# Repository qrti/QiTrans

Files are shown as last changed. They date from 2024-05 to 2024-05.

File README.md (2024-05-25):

# **QI Transmission**

### Wireless Energy Transmission
<br>

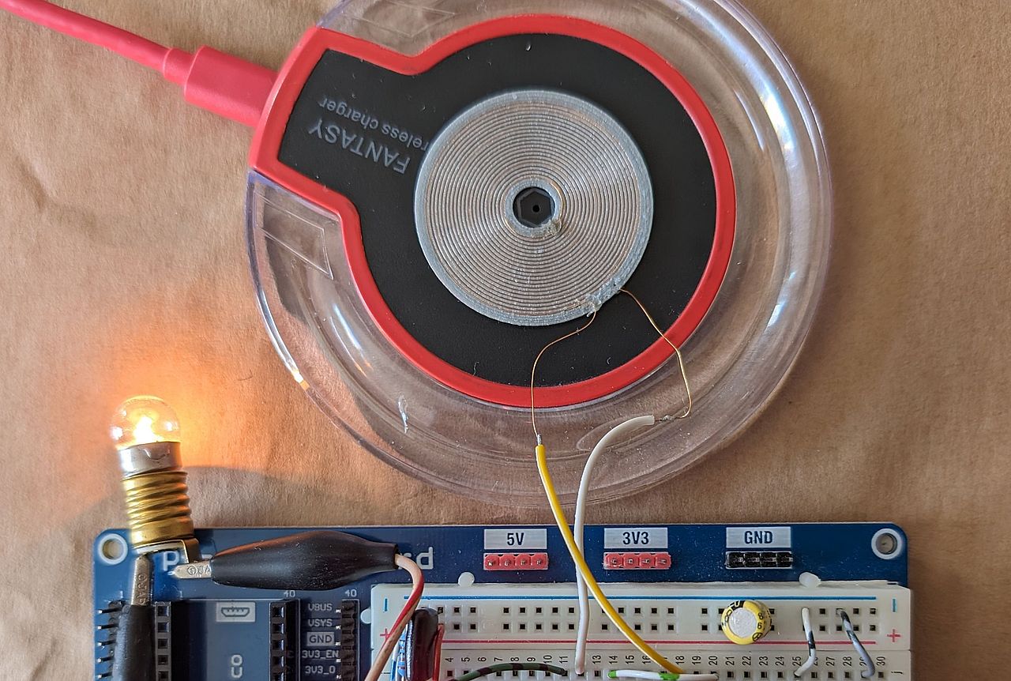
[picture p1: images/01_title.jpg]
<br>
<br>

## Description
Wireless chargers that comply with the Qi standard for charging mobile phones are inexpensive and widely available. Why not experiment a bit with the charger to wirelessly charge a (self-built) battery device, for example? Simply placing a coil on the charger to tap into the power is unfortunately not sufficient. A data transmission embedded in the energy flow according to the Qi protocol must initiate and then continuously maintain the power flow.

In this project, an inexpensive AVR controller with suitable hardware and software is used, and a simple method for manufacturing a flat coil is described.
<br>

## Soft- and Hardware
[**-> Source**](source)  

Breadboard Build, an old fashioned bulb is being lit  
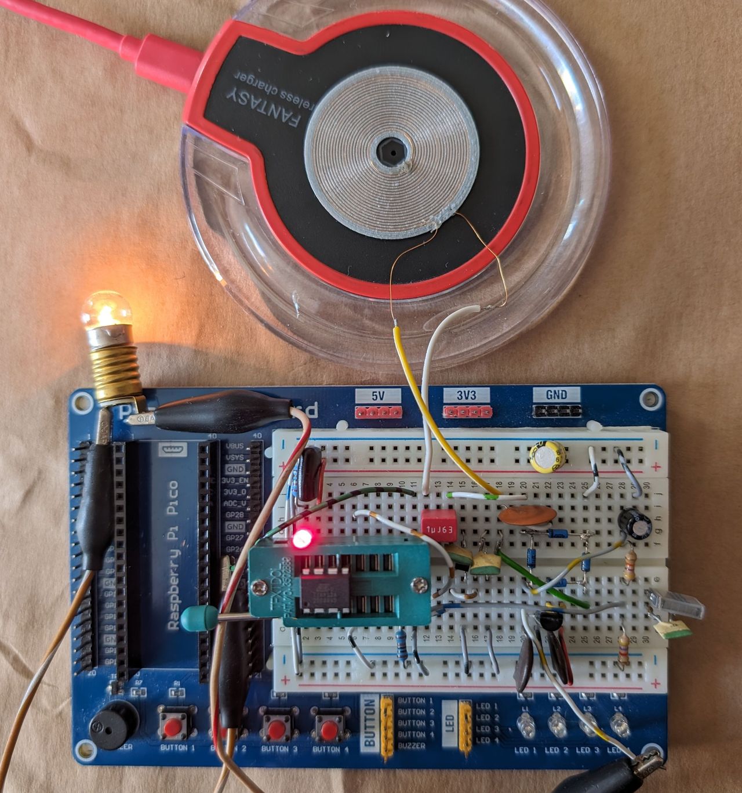
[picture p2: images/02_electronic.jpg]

<br>

Schematic (click to enlarge)  
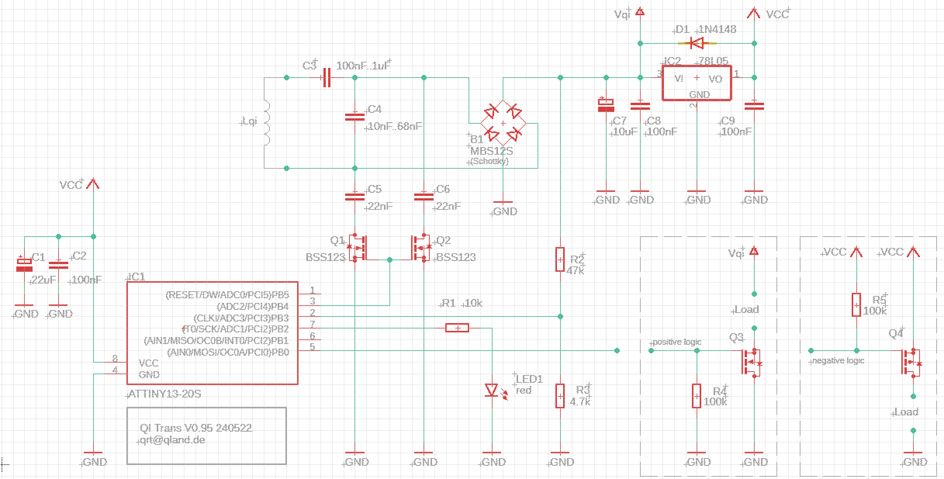
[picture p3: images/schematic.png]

<br>

# Flat Coil  
Two STL files for coils are in the repository, the 3d printer nozzle diameter  
for these prints must be 0.4 mm, you can try to fabricate more dense coils  
with 0.2 mm nozzles  
[-> wire 0.21 mm nozzle 0.4 mm](stl/qi_coil_021_04.stl)  
[-> wire 0.3 mm nozzle 0.4 mm](stl/qi_coil_03_04.stl)
<br>
<br>

Some examples for flat coils, a commercial available flat coil, a self winded  
round one a coil extracted from a hard disk and a self made oval one  
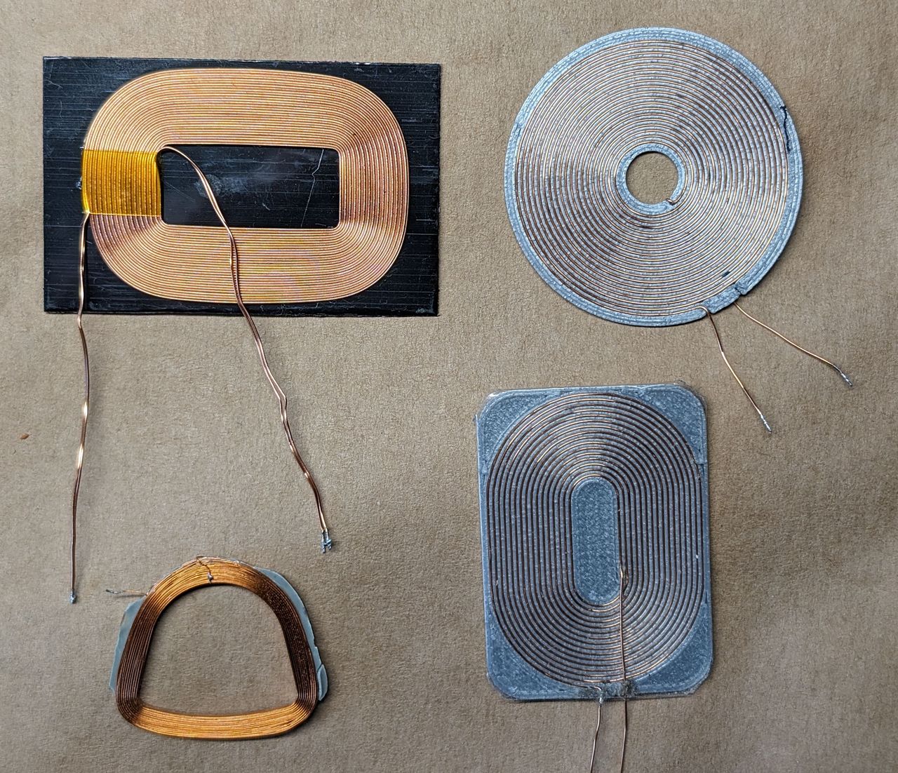
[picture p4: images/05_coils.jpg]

<br>

An easy method of winding a flat coil is to 3D print a carrier with grooves  
to sink in enameled copper wire, if diameters of wire and groove match, no  
glue is necessary to keep the wire on track  
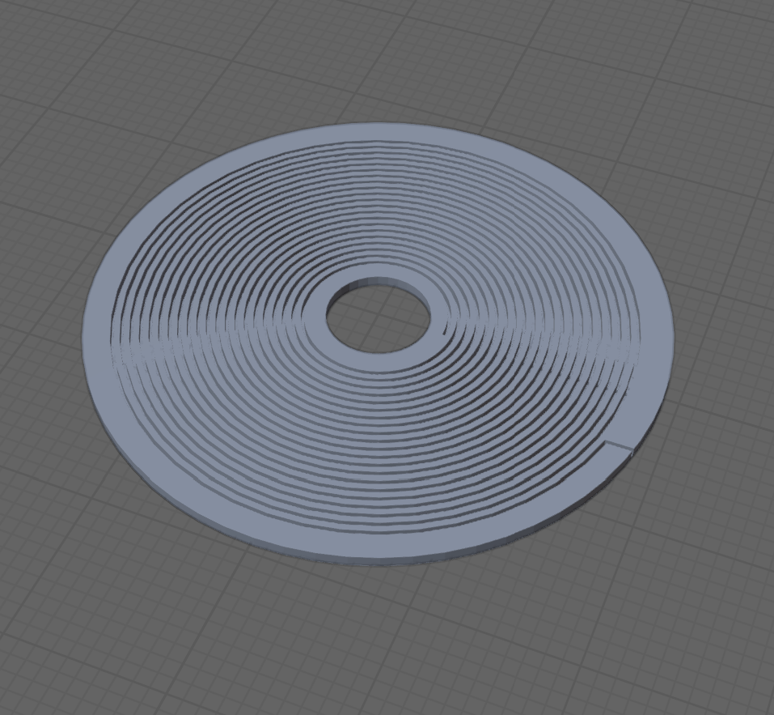
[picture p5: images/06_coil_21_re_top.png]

<br>  

Bottom side with groove to lead the wire outside  
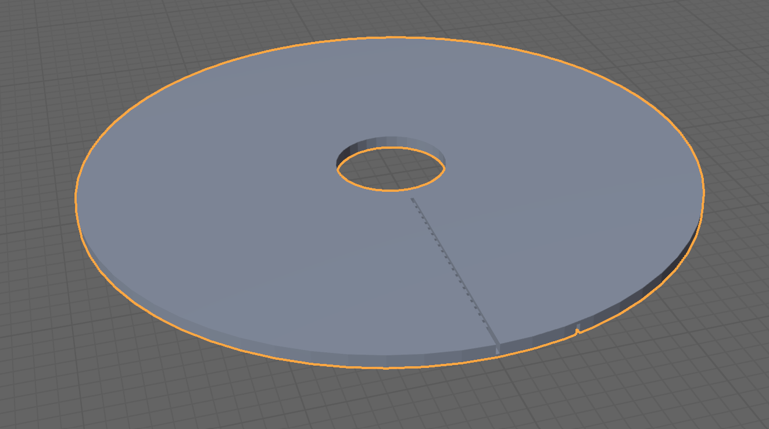
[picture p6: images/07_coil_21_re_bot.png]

<br>

While commercial available flat coils are able to deliver some ampere, these  
self made coils are cheap and easy to wind but will deliver some 100 mA only  
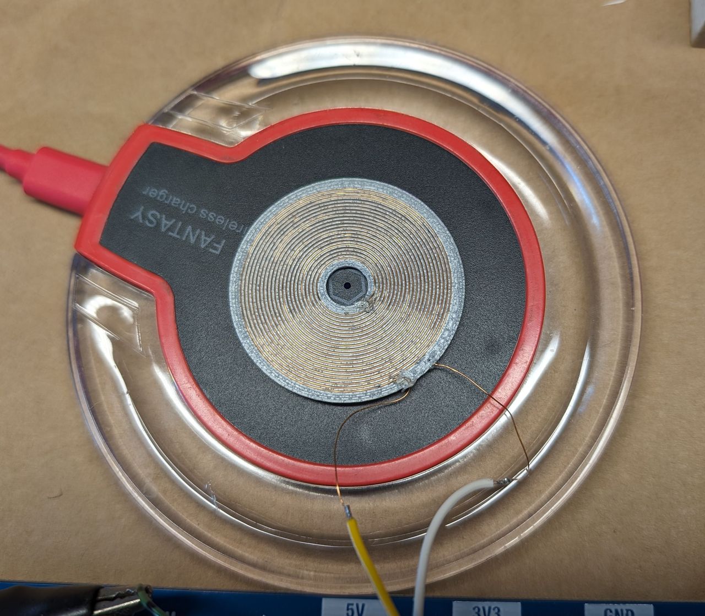
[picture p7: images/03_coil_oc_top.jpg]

<br>

Bottom side  
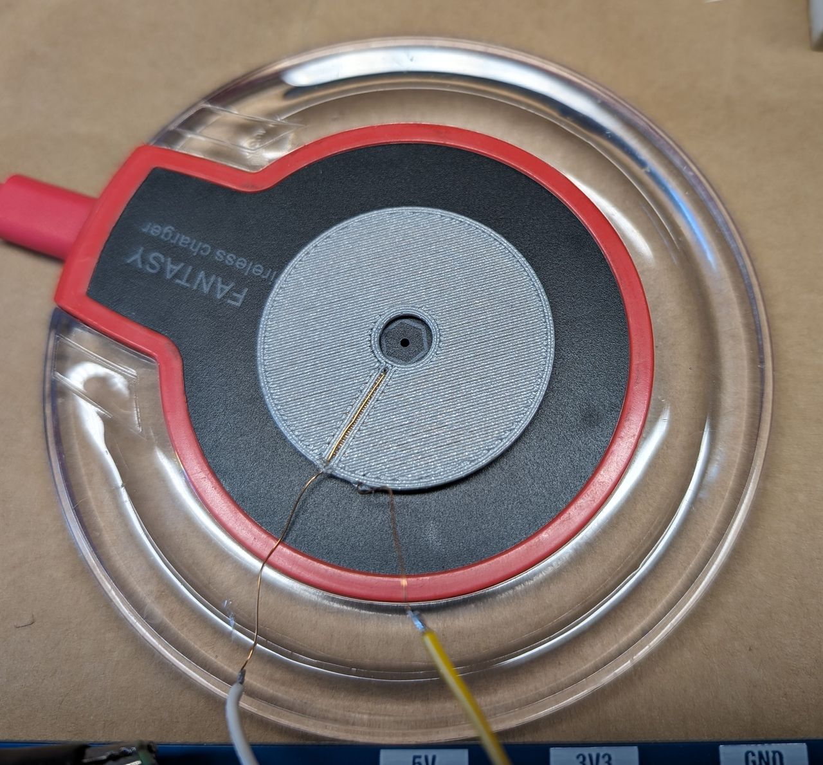
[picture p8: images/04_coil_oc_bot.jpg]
<br>
<br>

Ferro foils on the back of the flat coils will enhance efficiency of wireless  
energy transmission, only **pure** ferro foils for sticking magnets on it, not the  
self magnetic ones, will work  
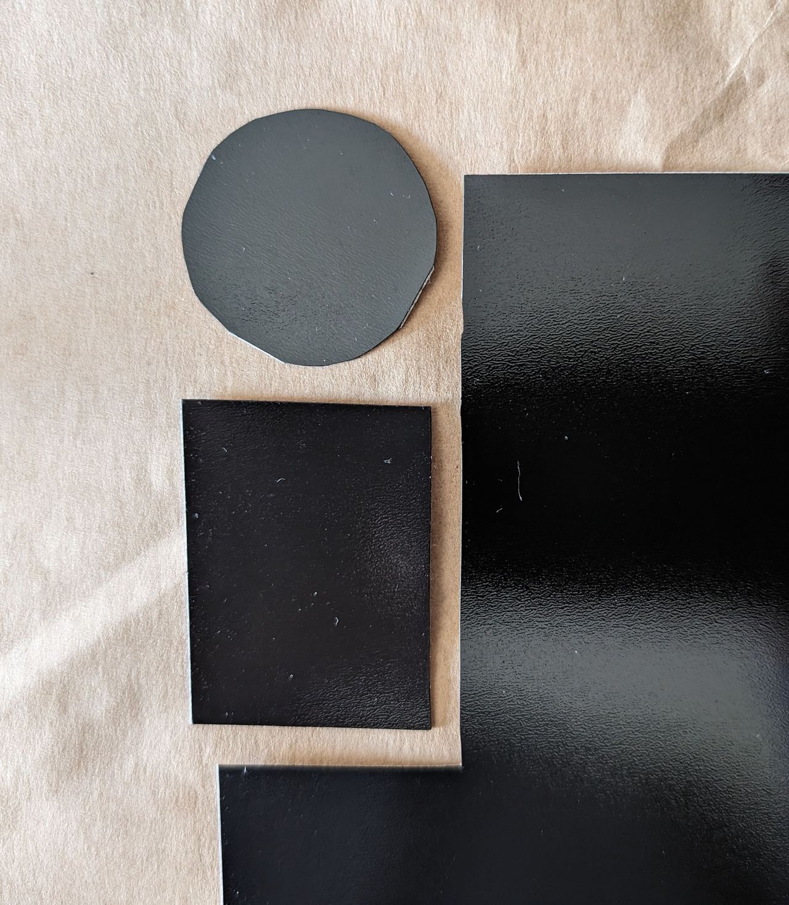
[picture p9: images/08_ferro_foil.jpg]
<br>
<br>

<br>
<br>

**Edited and Developed with vsCode**  
https://code.visualstudio.com/  

<br>

---

[qrt@qland.de](mailto:qrt@qland.de) 240524

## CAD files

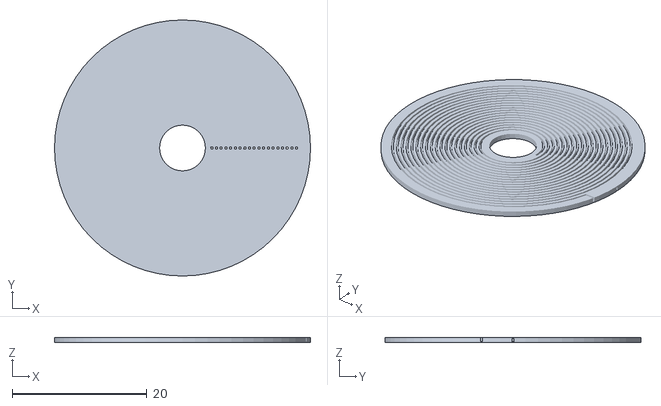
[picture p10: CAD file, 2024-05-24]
stl/qi_coil_03_04.stl
38.0 x 38.0 x 0.8

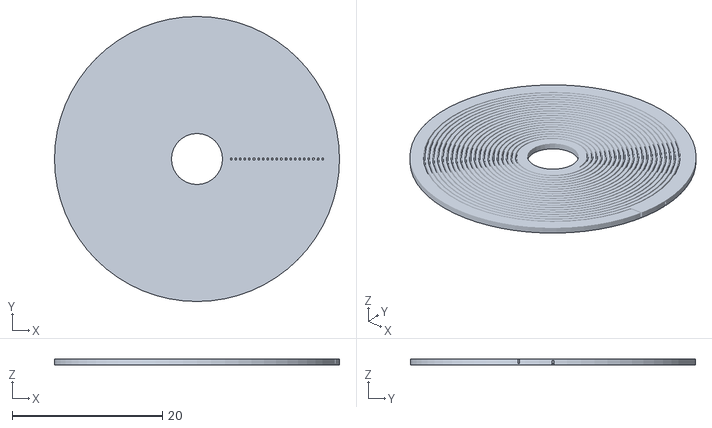
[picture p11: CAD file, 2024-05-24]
stl/qi_coil_021_04.stl
38.0 x 38.0 x 0.8

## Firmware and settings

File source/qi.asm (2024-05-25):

;qi.asm V0.9 QRT240524
;
;ATTINY13 - - - - - - - - - - - - - - - - - - - - - - - - - -
;fuse bits  76543210   low
;SPIEN      0|||||||   (default on)
;EESAVE      1||||||   (default off)
;WDTON        1|||||   (default off)
;CKDIV8        1||||   no clock div during startup
;SUT1..0        00||   00 - 14 CK / 01 - 14 CK + 4 ms /  / 10 - 14 CK + 64 ms
;CKSEL1..0        10   01 - 4.8 / 10 - 9.6 MHz system clock
;           01110010   0x72
;
;fuse bits     43210   high
;SELFPRGEN     1||||   (default off)
;DWEN           1|||   (default off)
;BODLEVEL1..0    10|   00 - 4.3 / 01 - 2.7 / 10 - 1.8 V / 11 - default off
;RSTDISBL          1   (default off)
;              11101   0xfd
;
;V0.9  initial version
;
;-------------------------------------------------------------------------------
;       logic           MOSFET      ground              U load      
; 0     negative        P           uC                  uC          
; 1     positive        N           drain of MOSFET     QI          
.define LOADLOGIC   1                   

;-------------------------------------------------------------------------------

;.device ATtiny13A
.include "tn13Adef.inc"

;-------------------------------------------------------------------------------

.cseg
.org $0000
rjmp main                               ;Reset Handler
;.org $0001
;rjmp EXT_INT0                           ;External Interrupt0 Handler
;.org $0002
;rjmp PCINT0                             ;Pin Change Interrrupt Handler
;.org $0003
;rjmp TIM0_OVF                           ;Timer0 Overflow Handler
;.org $0004
;rjmp EE_RDY                             ;EEPROM Ready Handler
;.org $0005
;rjmp ANA_COMP                           ;Analog Comparator Handler
;.org $0006
;rjmp TIM0_COMPA                         ;Timer0 Compare A
;.org $0007
;rjmp TIM0_COMPB                         ;Timer0 CompareB Handler
;.org $0008
;rjmp WATCHDOG                           ;Watchdog Interrupt Handler
;.org $0009
;rjmp ADC                                ;ADC Conversion Handler

;-------------------------------------------------------------------------------

.def    a0          =   r0              ;main registers set a
.def    a1          =   r1
.def    a2          =   r2
.def    a3          =   r3
.def    a4          =   r24             ;immediate
.def    a5          =   r25
.def    a6          =   r22
.def    a7          =   r23

.def    c0          =   r4              ;main register set c
.def    c1          =   r5
.def    c2          =   r6
.def    c3          =   r7
.def    c4          =   r16             ;immediate
.def    c5          =   r17
.def    c6          =   r18
.def    c7          =   r19

.def    srsave      =   r14             ;status register save
.def    NULR        =   r15             ;NULL value register
.def    FLAGR       =   r21             ;flag register

.def    bitState    =   r6              ;c2
.def    checkSum    =   r7              ;c3

.def    adcvL       =   r8              ;ADC current value
.def    adcvH       =   r9              ;

.def    sysTicL     =   r10             ;system ticker
.def    sysTicH     =   r11             ;
.def    recPowCnt   =   r12             ;received power cycle counter

.def    state       =   r20             ;state

;-------------------------------------------------------------------------------
;flags in FLAGR

;-------------------------------------------------------------------------------

.equ    QIP         =   PORTB           ;QI port
.equ    QIPP        =   PINB            ;   pinport
.equ    QIAD        =   PINB3           ;   ADC         in
.equ    QISIG       =   PINB4           ;               out

.equ    CTRLP       =   PORTB           ;control port
.equ    LOAD        =   PINB0           ;load           out
.equ    LED         =   PINB2           ;LED            out (positive logic)

;-------------------------------------------------------------------------------

.equ    data        =   SRAM_START

;-------------------------------------------------------------------------------
;Uad = Uqi / (R1 + R2) * R2
;Uad = Uref / 1023 * AD
;AD  = Uad * 1023 / Uref
;AD  = Uqi / (R1 + R2) * R2 * 1023 / Uref 
;
;AD = Uqi / (R1 + R2) * R2 * 1023 / Uref
;R1 = 47 k, R2 = 4.7 k, Uref = 1.1 V

.equ    DETECT_THRES        =   169             ;2.0 V
.equ    PING_THRES          =   296             ;3.5 V
.equ    TARGET_LEVEL        =   566             ;6.7 V      (Utarget - 78L05 dropout 1.7 V = 5 V)
.equ    ERROR_THRES         =   4               ;0.05 V

.equ    STATE_IDLE          =   0               ;state idle
.equ    STATE_PING          =   1               ;      ping
.equ    STATE_IDENT         =   2               ;      identification
.equ    STATE_CONF          =   3               ;      configuration
.equ    STATE_POWC          =   4               ;      power control
.equ    STATE_POWR          =   5               ;            receive
.equ    STATE_END           =   6               ;      end

.equ    PREAMBLE_BITS       =   16              ;number of preamble bits
.equ    EXTRA_PADDING       =   5               ;extra padding len
.equ    REC_POW_CYC         =   8               ;receive power cycle

;-------------------------------------------------------------------------------
;len, data ..., zero padding

sigStre:
.DB     2, 0x01, 0xff, 0

ident:
.DB     8, 0x71, 0x11, 0x10, 0x20, 0x01, 0x02, 0x03, 0x04, 0

config:
.DB     6, 0x51, 10, 0x00, 0x00, 0x43, 0x00, 0

conErr:
.DB     2, 0x03, 0x00, 0

recPow:
.DB     2, 0x04, 128, 0

endPow:
.DB     2, 0x02, 0x01, 0

;-------------------------------------------------------------------------------

main:
        ldi     a4,low(RAMEND)          ;set stack pointer
        out     SPL,a4                  ;to top of RAM


.if LOADLOGIC == 0
;                    --543210
        ldi     a4,0b00000001           ;LOAD off
        out     PORTB,a4                ;
.else
;                    --543210
        ldi     a4,0b00000000           ;LOAD off
        out     PORTB,a4                ;
.endif
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
